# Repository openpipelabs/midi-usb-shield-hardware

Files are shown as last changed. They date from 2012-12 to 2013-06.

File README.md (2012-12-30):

OpenPipe MIDI-USB Shield
========================

This is the PCB for the OpenPipe MIDI-USB Shield  
Format is EagleCAD schematic and board layout  

For more details, check out the product page at  
http://openpipe.cc/products/midi-usb-shield/

OpenPipe invests time and resources providing this open source design, 
please support OpenPipe and open-source hardware by purchasing 
products from OpenPipe!

License & Attribution
---------------------
Designed by OpenPipe (www.openpipe.cc).

Creative Commons Attribution-NonCommercial-ShareAlike license (CC BY-NC-SA)

http://creativecommons.org/licenses/by-nc-sa/3.0/  
http://creativecommons.org/licenses/by-nc-sa/3.0/legalcode

All text above must be included in any redistribution

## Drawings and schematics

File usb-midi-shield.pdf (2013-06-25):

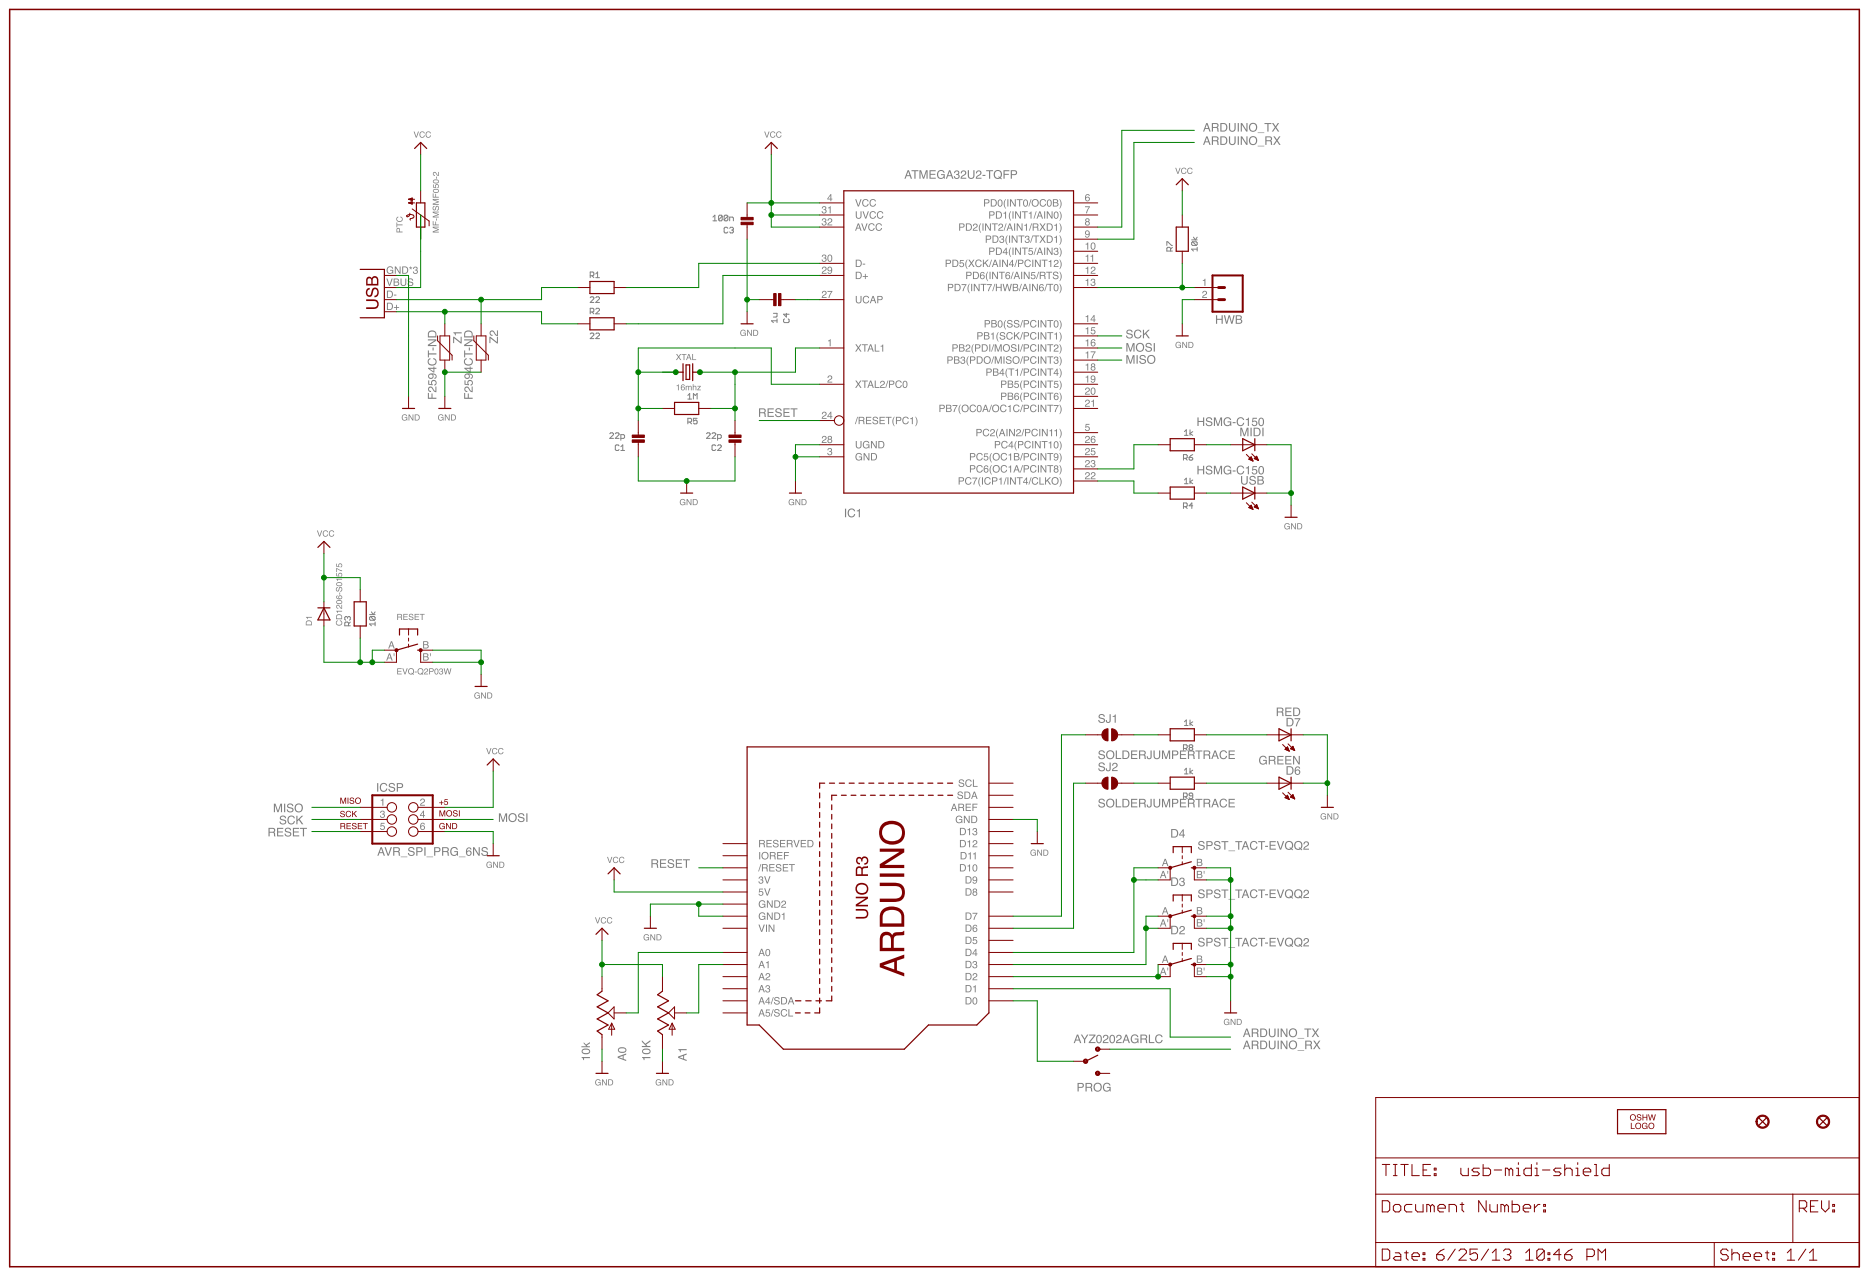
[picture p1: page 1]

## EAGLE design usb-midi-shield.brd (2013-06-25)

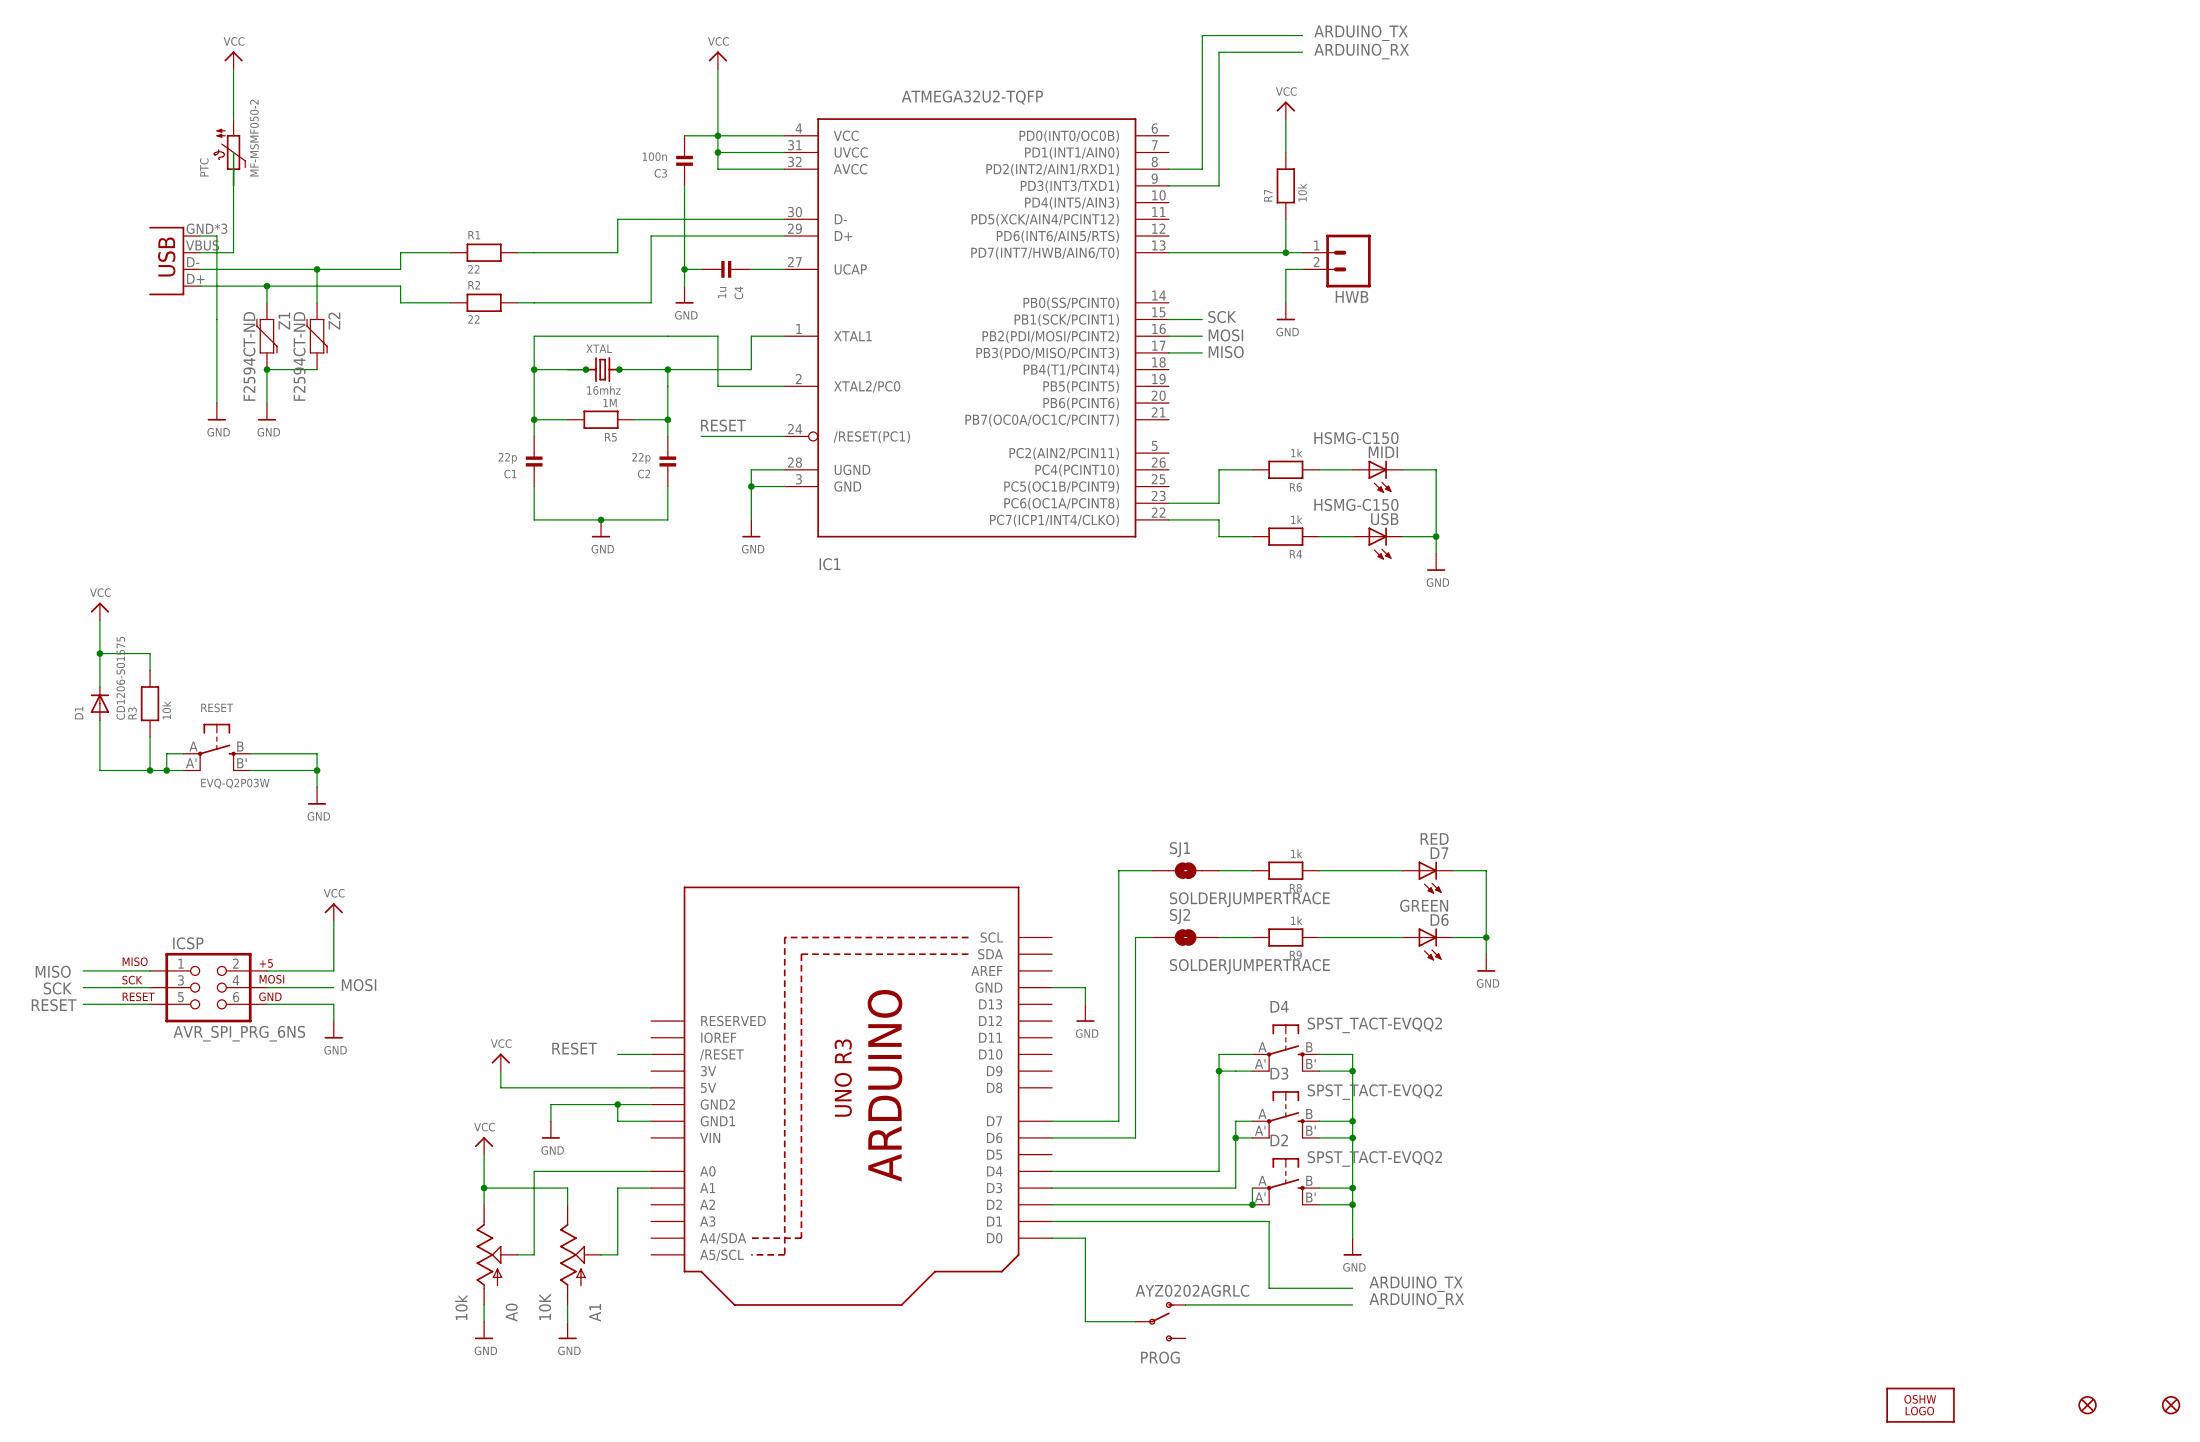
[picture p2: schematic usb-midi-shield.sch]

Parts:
A0: 10k; ALPS_POT
A1: 10K; ALPS_POT
C1, C2: 22p; 0603
C3: 100n; 0603
C4: 1u; 0603
D1: CD1206-S01575; SOD-123
D2, D3, D4: SPST_TACT-EVQQ2; EVQ-Q2
D6: GREEN; LED-1206
D7: RED; LED-1206
FID1, FID2: FIDUCIAL1.5X3; FIDUCIAL-1.5X3
HWB: M02LOCK; 1X02_LOCK
IC1: ATMEGA32U2-TQFP; TQFP32-08
ICSP: AVR_SPI_PRG_6NS; 2X3-NS
JP1: USB-MICROB
LOGO1: OSHW_LOGO_FILLX0350-NT; OSHW_FILLX350_NOTEXT
MIDI: HSMG-C150; LED-1206
PROG: AYZ0202AGRLC; AYZ0202
PTC: MF-MSMF050-2; PTC1812
R1, R2: 22; 0805
R3, R7: 10k; 0805
R4, R6, R8, R9: 1k; 0805
R5: 1M; 0805
RESET: EVQ-Q2P03W; EVQ-Q2
SJ1, SJ2: SOLDERJUMPERTRACE; SJ_2S-TRACE
U1: ARDUINOR3NODIM; ARDUINOR3-NODIM
USB: HSMG-C150; LED-1206
XTAL: 16mhz; HC49UP
Z1, Z2: F2594CT-ND; 0603-RES

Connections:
3V: U1.3V
ARDUINO_RX: IC1.9 (PD3(INT3/TXD1)), PROG.1 (O)
ARDUINO_TX: IC1.8 (PD2(INT2/AIN1/RXD1)), U1.D1
D-: IC1.29 (D+), R2.2
GND: A0.P$3 (A), A1.P$3 (A), C1.1, C2.1, C3.1, C4.2, D2.B (S), D2.B' (S1), D3.B (S), D3.B' (S1), D4.B (S), D4.B' (S1), D6.C, D7.C, HWB.2, IC1.3 (GND), IC1.28 (UGND), ICSP.6, JP1.GND, JP1.MT1 (GND), JP1.MT2 (GND), MIDI.C, RESET.B (S), RESET.B' (S1), U1.GND, U1.GND1, U1.GND2, USB.C, Z1.2, Z2.2
MISO: IC1.17 (PB3(PDO/MISO/PCINT3)), ICSP.1
MOSI: IC1.16 (PB2(PDI/MOSI/PCINT2)), ICSP.4
unnamed: HWB.1, IC1.13 (PD7(INT7/HWB/AIN6/T0)), R7.1
unnamed: C1.2, IC1.2 (XTAL2/PC0), R5.2, XTAL.1
unnamed: JP1.D+, R2.1, Z1.1
unnamed: C2.2, IC1.1 (XTAL1), R5.1, XTAL.2
unnamed: IC1.30 (D-), R1.2
unnamed: D2.A, D2.A' (P1), U1.D2
unnamed: D3.A, D3.A' (P1), U1.D3
unnamed: C4.1, IC1.27 (UCAP)
unnamed: JP1.VBUS, PTC.P$2 (2)
unnamed: IC1.23 (PC6(OC1A/PCINT8)), R6.2
unnamed: IC1.22 (PC7(ICP1/INT4/CLKO)), R4.2
unnamed: MIDI.A, R6.1
unnamed: R4.1, USB.A
unnamed: D4.A, D4.A' (P1), U1.D4
unnamed: JP1.D-, R1.1, Z2.1
unnamed: A1.P$2 (S), U1.A1
unnamed: A0.P$2 (S), U1.A0
unnamed: R8.2, SJ1.2
unnamed: D7.A, R8.1
unnamed: R9.2, SJ2.2
unnamed: D6.A, R9.1
unnamed: SJ2.1, U1.D6
unnamed: SJ1.1, U1.D7
unnamed: PROG.2, U1.D0
RESET: D1.A, IC1.24 (/RESET(PC1)), ICSP.5, R3.1, RESET.A, RESET.A' (P1), U1.RESET (/RESET)
SCK: IC1.15 (PB1(SCK/PCINT1)), ICSP.3
VCC: A0.P$1 (E), A1.P$1 (E), C3.2, D1.C, IC1.4 (VCC), IC1.31 (UVCC), IC1.32 (AVCC), ICSP.2, PTC.P$1 (1), R3.2, R7.2, U1.5V
VIN: U1.VIN

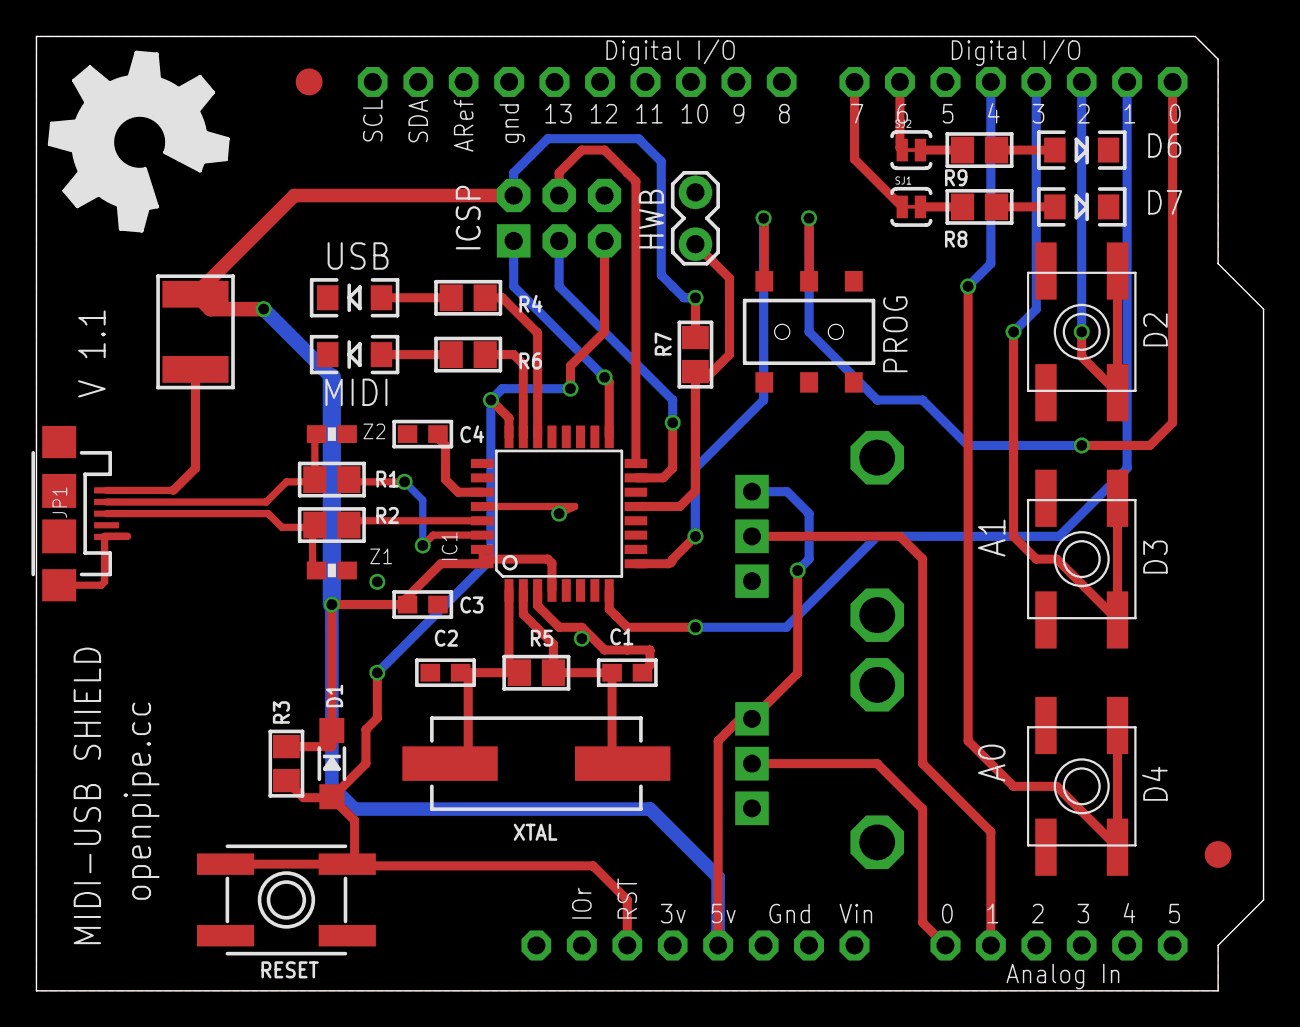
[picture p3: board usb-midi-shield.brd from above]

Board: 2 copper layers, 68.6 x 53.3 mm, 39 parts (0 on the bottom side), 33 nets.

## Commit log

2012-12-23 initial hardware version
    [usb-midi-shield.brd, usb-midi-shield.sch]
2013-06-25 changed to v1.1
    [usb-midi-shield.brd, usb-midi-shield.sch]

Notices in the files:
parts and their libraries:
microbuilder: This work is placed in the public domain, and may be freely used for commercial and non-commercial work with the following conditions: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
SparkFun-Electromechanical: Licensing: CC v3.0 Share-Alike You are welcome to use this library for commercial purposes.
